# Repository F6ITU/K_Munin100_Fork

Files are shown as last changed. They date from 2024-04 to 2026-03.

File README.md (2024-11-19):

# MUNIN-100
MUNIN 100 is a 100W HF Power Amplifier using the MRF101AN/MRF101BN at 48V DC supply voltage.

Munin amps belongs to the OpenHPSDR familly

Original design by Kjell LA2NI

Some small mods by f6itu (just some kicad settings and design)

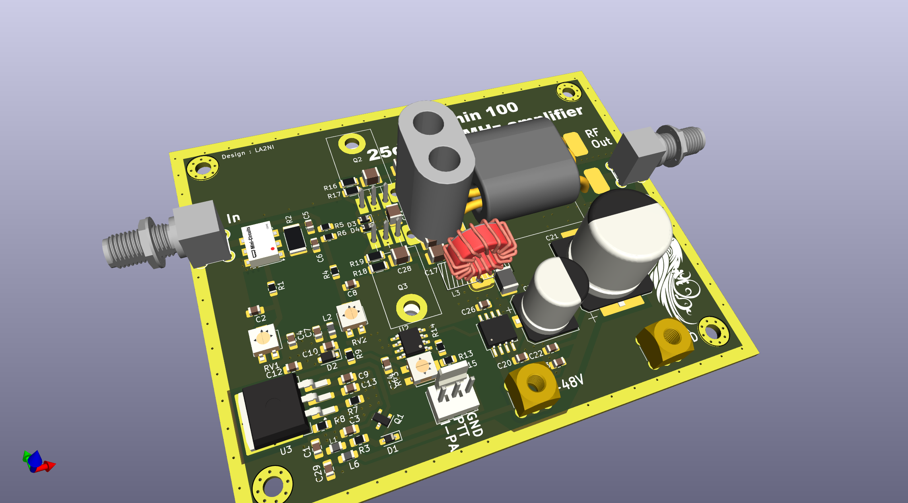
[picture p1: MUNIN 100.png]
Munin, a 100W HF linear amplifier


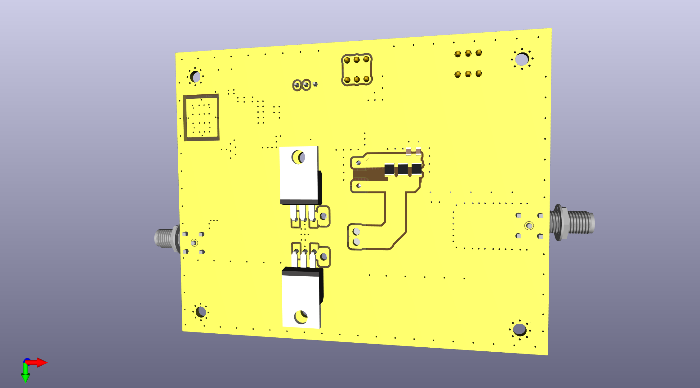
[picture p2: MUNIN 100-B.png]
Munin, a 100W HF linear amplifier


This amplifier board is part of a set consisting of a 100 W LD-Mos based RF power amplifier (Munin 100), 
a medium power Zolotarev low pass filter (600 or 1500 W), an Automatic Antenna Tuner (ATU) nickname « Aries » 
and a 4 port antenna switch.

But the power level is compatible with the traditional "Alexiares" filter frontend, (https://wiki.electrolab.fr/Projets:Lab:2017:Peripheriques_Angelia )
in lpf/hpf configuration or it's up to date evolution (lpf and dual bpf) 

All these developments are the work and intellectual property of Kjell Karlsen LA2NI and Laurence Barker G8NJJ.

This original work can be downloaded from

https://github.com/LA2NI/

https://github.com/laurencebarker

This board was originally developed in 2022 by Kjell LA2NI.

This fork (convertion/translation) is placed under the CERN Open source/ Open hardware Licence.

Kicad is an Opensource EDA software maintained by the European Reseach Center CERN (Conseil européen pour la recherche nucléaire)

The original work is protected by the TAPR Open Hardware licence

Mythology and openHPSDR codename conventions

Munin and Hugin are the two "messenger" ravens of the Norse god Odin - just as Hermes is the messenger-god in Greek mythology, 
and the masterpiece of the OpenHPSDR architecture 

This LDMoS transistor-based amplifier brings speech over the great distances of the "Midgard" of the waves

# Work in progress

Use these files at your own risk (that's the moto of ham homebrew)

As far as I know, this amp has never been build. Some minor KiCad errors and design hickups have been fix

The  the 1:4 input impedance transformer could be replaced with a simple coax strap (with or without ferrite core) as the combined impedance of the two transistors is approximately 50 Ohms at 55 MHz. On lower frequencies, the value of Z
is determined by the value of R4-R11 (22 Ohms, not yet tested) 

the pcb has been design to accomodate two feedback techniques : 
- coupling from a "secondary" winding in the first TLT
- or direct pickup of the drain signal fia a C & R feedback circuit

Value or R16/19 should be changed accordingly 

the first TLT MUST be soldered as short as possible. That's the reason why the third beta of this pcb uses a fat power trace located on the bottom Cu side of the board. 

For more information, please consider reading 

https://ludens.cl/Electron/50Wamp/50Wamp.html

and 

https://ludens.cl/Electron/RFamps/RFamps.html

(chapter "Broadband push-pull amplifiers"

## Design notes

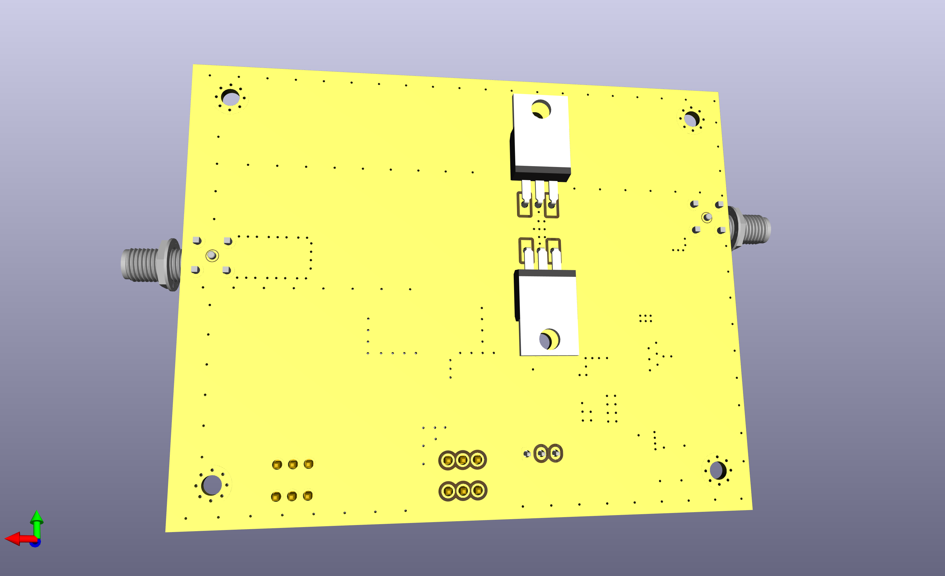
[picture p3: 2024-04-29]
MUNIN 100-C.png

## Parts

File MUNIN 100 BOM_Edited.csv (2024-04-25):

Id | Designator | Package | Quantity | Designation | Part number | Alternative PN
1 | C1 | C_0805_2012Metric | 1 | 100nF
2 | Q3 | TO-220-3_Horizontal_TabDown_SMD | 1 | MRF101BN | MRF101BN
3 | R1,R4,R15 | R_0805_2012Metric_Pad1.20x1.40mm_HandSolder | 3 | 100R
4 | U2 | Diodes_PSOP-8 | 1 | LM358
5 | C8,C7,C19,C23,C9,C5,C3,C2,C20,C10,C29,C13,C6,C18,C4 | C_0805_2012Metric_Pad1.18x1.45mm_HandSolder | 15 | 100nF
6 | L1,L2,L6 | L_0805_2012Metric_Pad1.05x1.20mm_HandSolder | 3 | L_Core_Ferrite_Small | BLM21SP102SN1D
7 | C12,C24 | C_0805_2012Metric_Pad1.18x1.45mm_HandSolder | 2 | 1u |  |  | .
8 | L4 | L_1812_4532Metric | 1 | Ferrite | FBMH4532HM681-T | HI1806T600R-10
9 | C14,C15,C17,C16 | C_1210_3225Metric_Pad1.33x2.70mm_HandSolder | 4 | 100n/500V
10 | C26 | C_0805_2012Metric_Pad1.18x1.45mm_HandSolder | 1 | 1n
11 | R7 | R_0805_2012Metric_Pad1.20x1.40mm_HandSolder | 1 | 240R
12 | IC1 | SO-8_5.3x6.2mm_P1.27mm | 1 | ACHS-7123
13 | R18,R16,R17,R19 | R_1206_3216Metric | 4 | TBD
14 | C25 | CP_Elec_10x14.3 | 1 | 220uF/63V | EEV-FK1J221Q | Panasonic
15 | TR1 | Mini-Circuits_CD542_H2.84mm | 1 | ADT4-1WT | ADT4-1WT+ | Mini Circuits
16 | D1 | D_MELF | 1 | BAT54J
17 | C11 | C_1210_3225Metric | 1 | TBD
19 | D3,D4 | D_0805_2012Metric | 2 | CDSOD323-T03CT-NO
20 | C21 | CP_Elec_16x17.5 | 1 | 560u/63V | EEE-TP1J561V | Panasonic
21 | R10,R12,R11 | R_1210_3225Metric | 3 | 4R7/1W
22 | L5 | L_1812_4532Metric | 1
23 | C27,C28 | C_0805_2012Metric | 2 | 100nH |  | 1
24 | J3 | PinHeader_1x03_P2.54mm_Horizontal | 1 | Conn_01x03_Male
25 | RV3 | Potentiometer_Bourns_3214G_Horizontal | 1 | 1K | 3214G-1-102E
26 | RV1,RV2 | Potentiometer_Bourns_3214G_Horizontal | 2 | 5K | 3214G-1-502E
27 | J1,J2 | SMA_Amphenol_132291_Vertical | 1 | SMA | 142-0701-201 | CONSMA002-L-G
28 | Q2 | TO-220-3_Horizontal_TabDown_SMD | 1 | MRF101AN | MRF101AN
29 | D2 | D_0603_1608Metric | 1 | 5.1V
30 | J4 | PinHeader_1x04_P2.54mm_Horizontal | 1 | 3-647630-4
31 | TLT2,TLT1 | TLT_94_3 | 2 | FT94-61 or FT82-61 | Kitsandparts.com | Reichelt Elektron.
32 | U1 | TO-263-3_TabPin2 | 1 | TL783CKTT | TL783CKTT
33 | R6,R5 | R_0805_2012Metric_Pad1.20x1.40mm_HandSolder | 2 | 1R
34 | Q1 | SOT-23 | 1 | ISS55EP06LMXTSA1 | ISS55EP06LMXTSA1
35 | R14 | R_0805_2012Metric_Pad1.20x1.40mm_HandSolder | 1 | 27K
36 | R9 | R_0805_2012Metric_Pad1.20x1.40mm_HandSolder | 1 | 1K
37 | C22 | C_0805_2012Metric_Pad1.18x1.45mm_HandSolder | 1 | 10u
38 | R3 | R_0805_2012Metric_Pad1.20x1.40mm_HandSolder | 1 | 10k
39 | R13 | R_0805_2012Metric_Pad1.20x1.40mm_HandSolder | 1 | 10K | CRM2512-FX-12R0ELF
40 | R2 | R_2512_6332Metric | 1 | 12R/2W
41 | R8 | R_0805_2012Metric_Pad1.20x1.40mm_HandSolder | 1 | 82R
42 | L3 | FT_50_1 | 1 | FT50-43 | Kitsandparts.com
 |  |  | 1

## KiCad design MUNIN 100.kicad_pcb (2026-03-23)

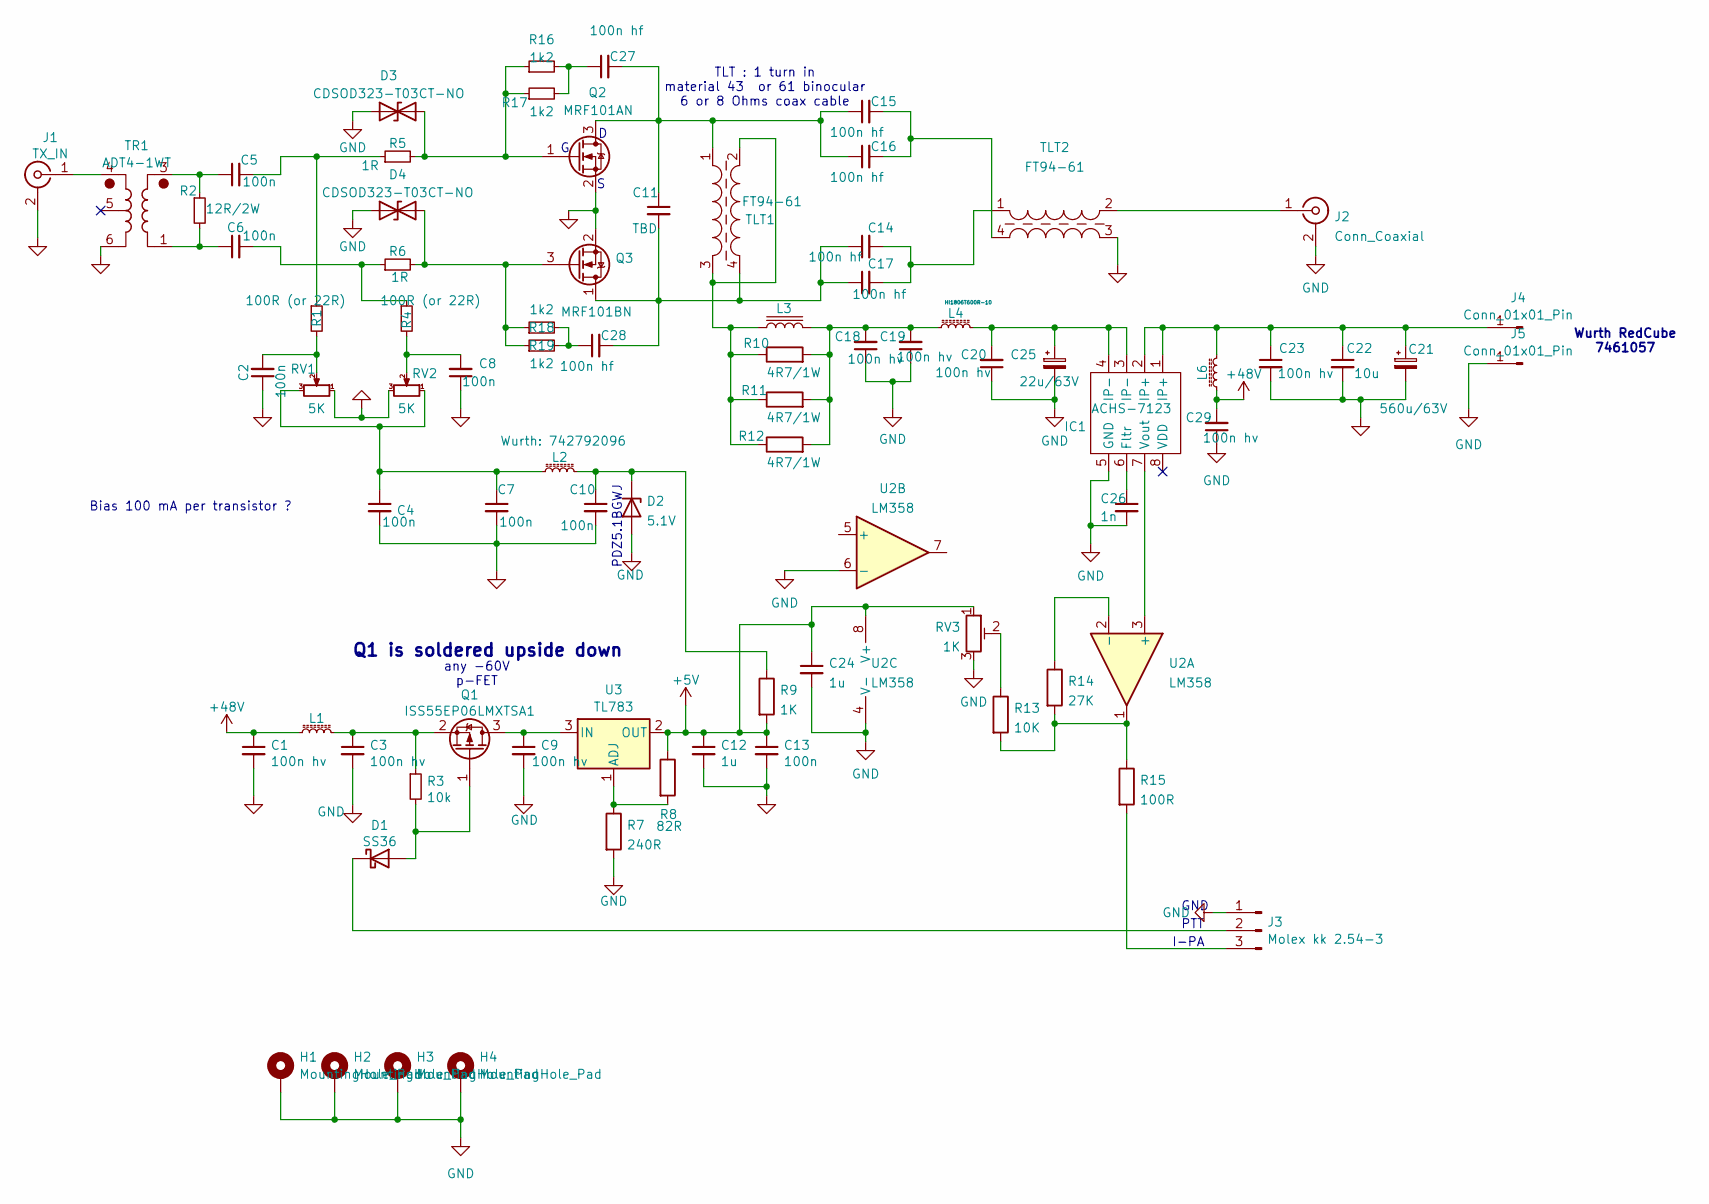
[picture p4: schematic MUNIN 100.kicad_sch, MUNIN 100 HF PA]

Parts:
C1, C3, C9, C18, C19, C20, C23, C29: 100n hv; C_0805_2012Metric_Pad1.18x1.45mm_HandSolder
C2, C4, C5, C6, C7, C8, C10, C13: 100n; C_0805_2012Metric_Pad1.18x1.45mm_HandSolder
C11: TBD; C_1210_3225Metric
C12, C24: 1u; C_0805_2012Metric_Pad1.18x1.45mm_HandSolder
C14, C15, C16, C17, C27, C28: 100n hf; C_1210_3225Metric_Pad1.33x2.70mm_HandSolder
C21: 560u/63V; CP_Elec_16x17.5
C22: 10u; C_0805_2012Metric_Pad1.18x1.45mm_HandSolder
C25: 22u/63V; CP_Elec_10x14.3
C26: 1n; C_0805_2012Metric_Pad1.18x1.45mm_HandSolder
D1: SS36; D_SOD-323_HandSoldering
D2: 5.1V; D_SOD-123F
D3, D4: CDSOD323-T03CT-NO; D_0805_2012Metric
H1, H2, H3, H4: MountingHole_Pad; MountingHole_3.2mm_M3_Pad_Via
IC1: ACHS-7123; SO-8_5.3x6.2mm_P1.27mm
J1: TX_IN; SMA_PINS
J2: Conn_Coaxial; SMA_PINS
J3: Molex kk 2.54-3; Molex_KK-254_AE-6410-03A_1x03_P2.54mm_Vertical
J4, J5: Conn_01x01_Pin; 7461057
L1: 742792096; L_0805_2012Metric_Pad1.05x1.20mm_HandSolder
L2: Wurth: 742792096; L_0805_2012Metric_Pad1.05x1.20mm_HandSolder
L3: FT-50-43; T50_V_smd
L4: HI1806T600R-10; L_1812_4532Metric
L6: L_Core_Ferrite_Small; L_0805_2012Metric_Pad1.05x1.20mm_HandSolder
Q1: ISS55EP06LMXTSA1; SOT-23
Q2: MRF101AN; TO-220-3_Horizontal_TabDown_SMD
Q3: MRF101BN; TO-220-3_Horizontal_TabDown_SMD
R1, R4: 100R (or 22R); R_0805_2012Metric_Pad1.20x1.40mm_HandSolder
R2: 12R/2W; R_2512_6332Metric
R3: 10k; R_0805_2012Metric_Pad1.20x1.40mm_HandSolder
R5, R6: 1R; R_0805_2012Metric_Pad1.20x1.40mm_HandSolder
R7: 240R; R_0805_2012Metric_Pad1.20x1.40mm_HandSolder
R8: 82R; R_0805_2012Metric_Pad1.20x1.40mm_HandSolder
R9: 1K; R_0805_2012Metric_Pad1.20x1.40mm_HandSolder
R10, R11, R12: 4R7/1W; R_1210_3225Metric
R13: 10K; R_0805_2012Metric_Pad1.20x1.40mm_HandSolder
R14: 27K; R_0805_2012Metric_Pad1.20x1.40mm_HandSolder
R15: 100R; R_0805_2012Metric_Pad1.20x1.40mm_HandSolder
R16, R17, R18, R19: 1k2; R_1206_3216Metric
RV1, RV2: 5K; Potentiometer_Bourns_3214X_Vertical
RV3: 1K; Potentiometer_Bourns_3214X_Vertical
TLT1: FT94-61; TLT
TLT2: FT94-61; Dual_FB-61-4852
TR1: ADT4-1WT; Mini-Circuits_CD542_H2.84mm
U2: LM358; SOIC-8_3.9x4.9mm_P1.27mm
U3: TL783; TO-263-3_TabPin2

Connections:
+5V: C12.1, C13.1, C24.1, R8.1, R9.2, RV3.1, U2.8 (V+), U3.2 (OUT)
+48V: C1.1, C29.2, L1.1, L6.1
GND: C1.2, C2.1, C3.2, C4.2, C7.2, C8.1, C9.2, C10.2, C12.2, C13.2, C18.1, C19.1, C20.1, C21.2, C22.2, C23.2, C24.2, C25.2, C26.2, C29.1, D2.2 (A), D3.1 (A1), D4.1 (A1), H1.1, H2.1, H3.1, H4.1, IC1.5 (GND), J1.2 (Ext), J2.2 (Ext), J3.1, J5.1, Q2.2 (S), Q3.2 (S), R7.2, RV1.1, RV2.3, RV3.3, TLT2.3, TR1.6, U2.4 (V-), U2.6 (-)
unnamed: C2.2, R1.2, RV1.2
unnamed: C4.1, C7.1, L2.1, RV1.3, RV2.1
unnamed: C5.1, R2.1, TR1.3
unnamed: C5.2, R1.1, R5.1
unnamed: C6.1, R2.2, TR1.1
unnamed: C6.2, R4.1, R6.1
unnamed: C8.2, R4.2, RV2.2
unnamed: C14.2, C17.2, TLT2.1
unnamed: C15.2, C16.2, TLT2.4
unnamed: C18.2, C19.2, L3.2, L4.1, R10.2, R11.2, R12.2
unnamed: C20.2, C25.1, IC1.3 (IP-), IC1.4 (IP-), L4.2
unnamed: C27.1, R16.2, R17.2
unnamed: C28.1, R18.2, R19.2
unnamed: D1.2 (A), Q1.1 (G), R3.2
unnamed: D1.1 (K), J3.2
unnamed: C10.1, D2.1 (K), L2.2, R9.1
unnamed: D3.2 (A2), Q2.1 (G), R5.2, R16.1, R17.1
unnamed: D4.2 (A2), Q3.3 (G), R6.2, R18.1, R19.1
unnamed: C26.1, IC1.6 (Fltr)
unnamed: IC1.7 (Vout), U2.3 (+)
unnamed: J1.1 (In), TR1.4
unnamed: J2.1 (In), TLT2.2
unnamed: J3.3, R15.2
unnamed: C21.1, C22.1, C23.1, IC1.1 (IP+), IC1.2 (IP+), J4.1, L6.2
unnamed: L3.1, R10.1, R11.1, R12.1, TLT1.2, TLT1.3
unnamed: C9.1, Q1.3 (D), U3.3 (IN)
unnamed: C3.1, L1.2, Q1.2 (S), R3.1
unnamed: C11.1, C15.1, C16.1, C27.2, Q2.3 (D), TLT1.1
unnamed: C11.2, C14.1, C17.1, C28.2, Q3.1 (D), TLT1.4
unnamed: R13.1, RV3.2
unnamed: R13.2, R14.2, R15.1, U2.1
unnamed: R14.1, U2.2 (-)
unnamed: R7.1, R8.2, U3.1 (ADJ)

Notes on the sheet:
Q1 is soldered upside down
PDZ5.1BGWJ
GND
TLT : 1 turn in material 43 or 61 binocular 6 or 8 Ohms coax cable
PTT
Bias 100 mA per transistor ?
Wurth RedCube 7461057
I-PA
any -60V p-FET

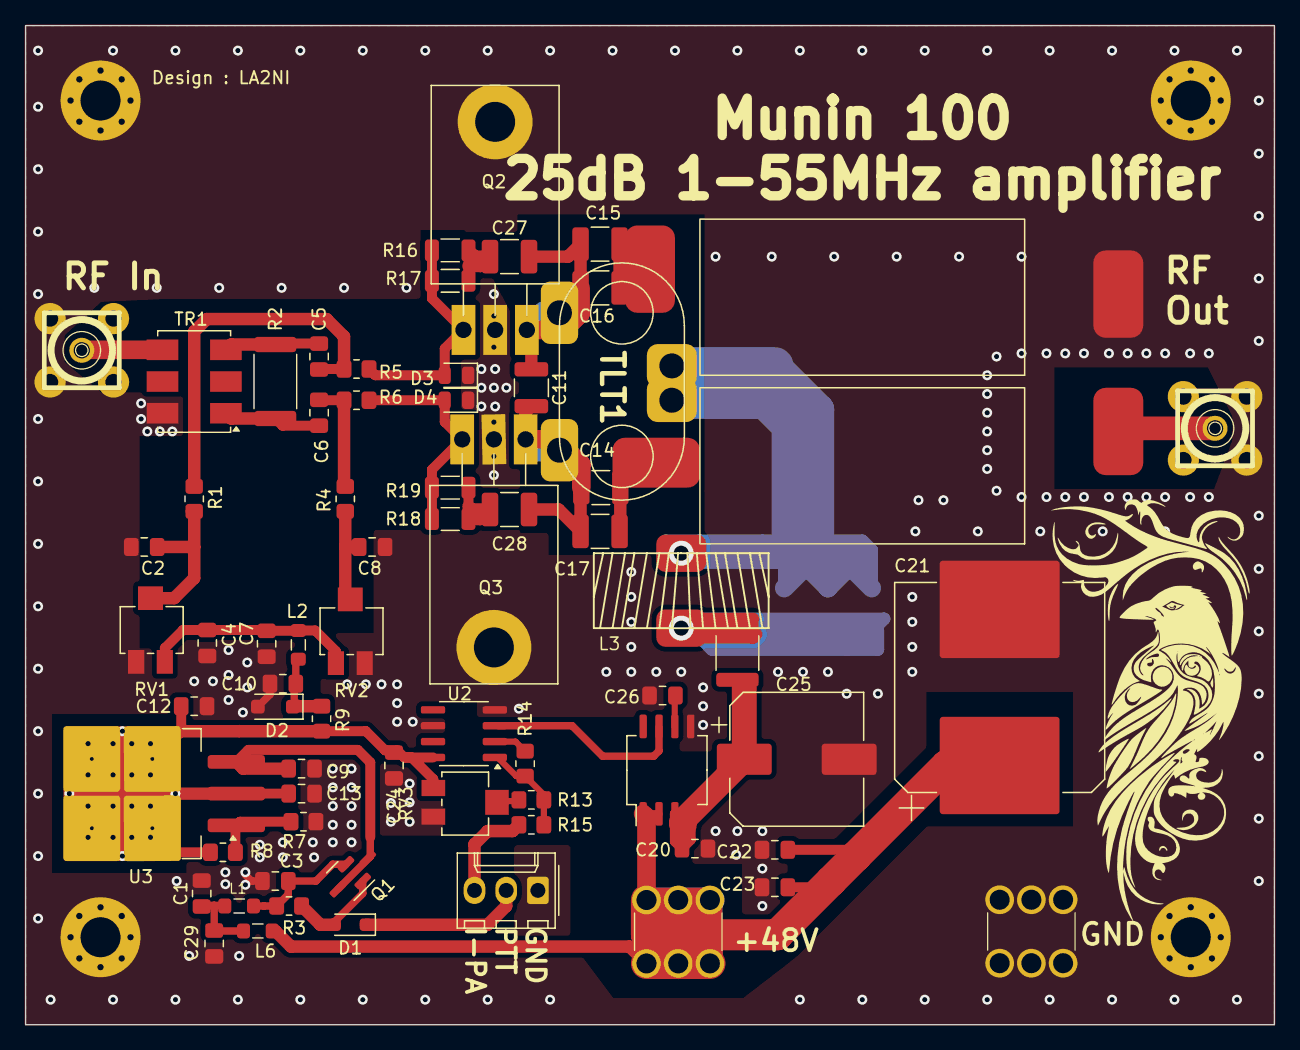
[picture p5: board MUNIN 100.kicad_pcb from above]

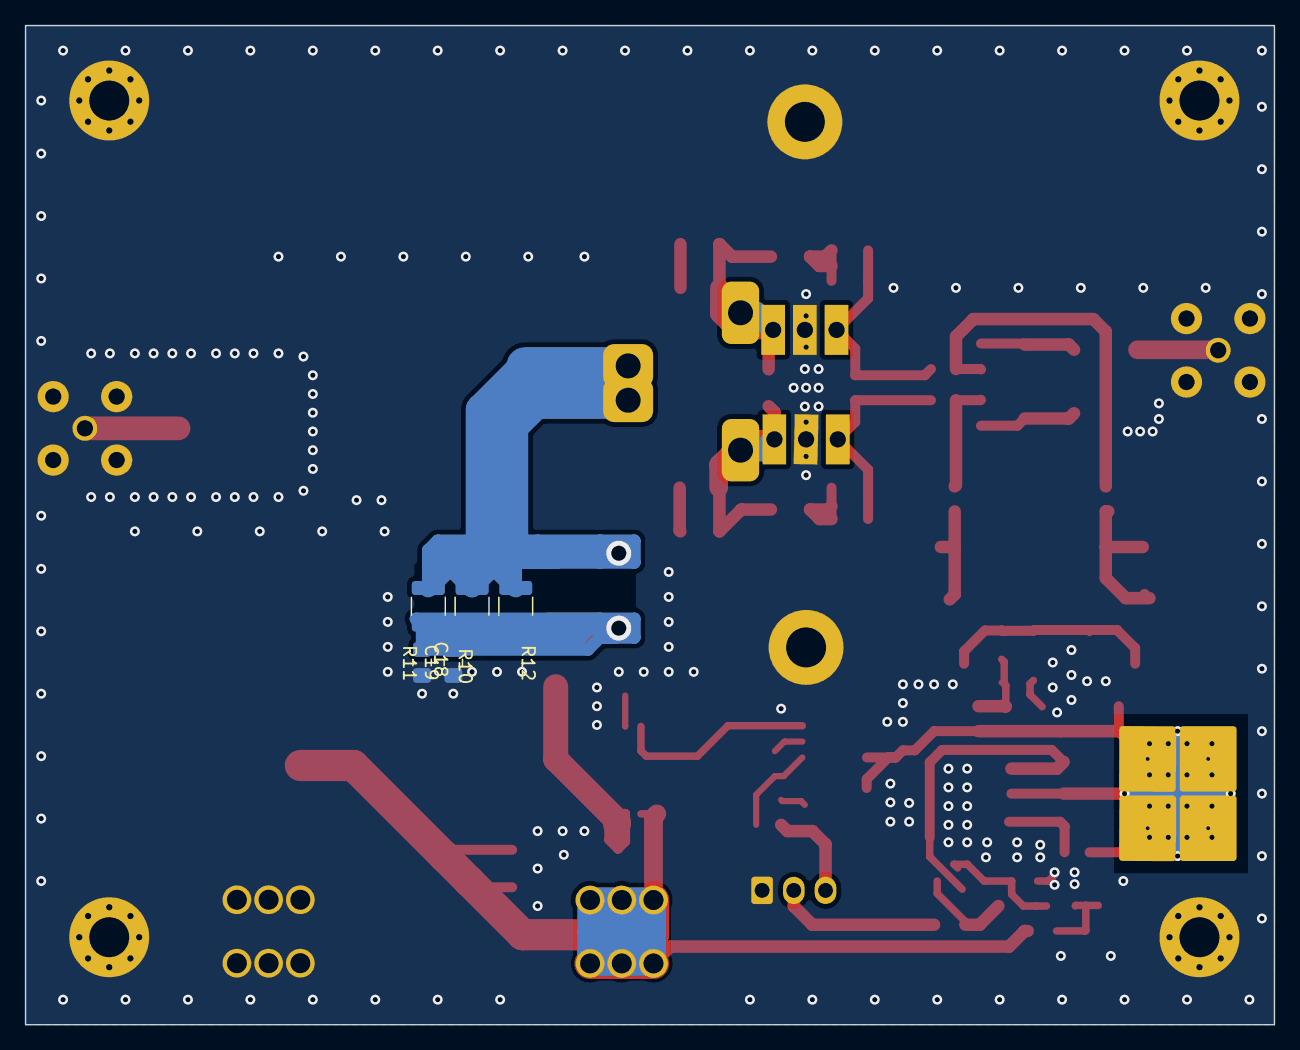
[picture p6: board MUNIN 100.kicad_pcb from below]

Board: 2 copper layers, 100.0 x 80.0 mm, 78 parts (5 on the bottom side), 36 nets.

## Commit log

2024-04-21 Munin 400 mod with MRF101 AN/BN
    [73204-5213.stp, K_Munin100.kicad_pcb, K_Munin100.kicad_sch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]
2024-04-25 former fork outdated, LA2NI's amp used as main
    [73204-5213.stp, Bifilar_xformer.kicad_pcb, K_Munin100.kicad_pcb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]
2024-04-29 first pcb release
    [MUNIN 100-B_Cu.gbl, MUNIN 100-B_Mask.gbs, MUNIN 100-Edge_Cuts.gm1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]
2024-05-14 ibom and gerber added, first prototype
    [MUNIN 100.kicad_pcb]
2024-06-05 minor errors fixed, Gerber is out of date
    [Bifilar_xformer.kicad_pcb, MUNIN 100.kicad_pcb, MUNIN 100.kicad_sch]
2024-06-23 new 48V trace
    [MUNIN 100.kicad_pcb, MUNIN 100.kicad_sch]
2024-06-26 48V rail, kicad 8.03, no new gerber
    [MUNIN 100.kicad_pcb]
2024-11-19 third release, new power TLT
    [MUNIN 100-B_Cu.gbl, MUNIN 100-B_Mask.gbs, MUNIN 100-Edge_Cuts.gm1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]
2026-03-23 kicad10 update, minor schematic changes
    [MUNIN 100.kicad_pcb, MUNIN 100.kicad_sch]
